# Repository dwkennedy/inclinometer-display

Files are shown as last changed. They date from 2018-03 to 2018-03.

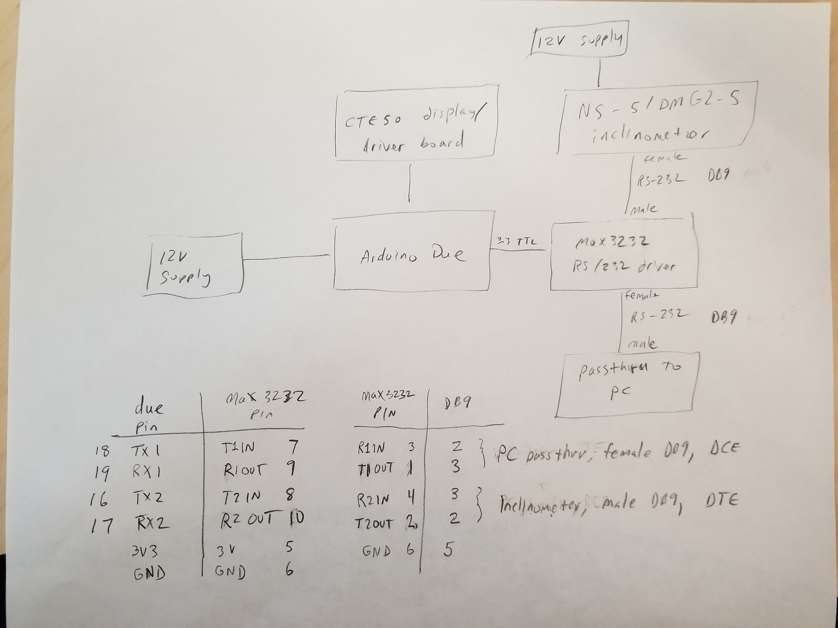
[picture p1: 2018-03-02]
inclinometer display block diagram and pinouts.jpg

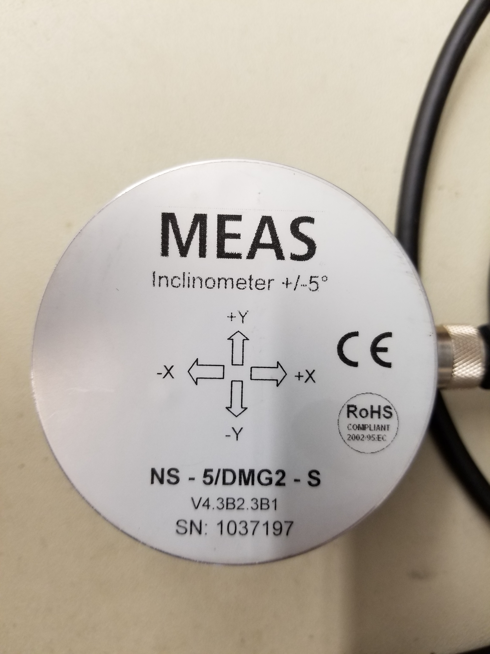
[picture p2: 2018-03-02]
measurement specialties inclinometer device.jpg

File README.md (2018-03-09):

# inclinometer-display
Device to display output from measurement specialties inclinometer

This device provides a graphical display of inclinometer output for leveling truck mounted RADAR systems (and anything else
one might desire)

Hardware requirements:
     Arduino DUE or similar.  I used a sainsmart clone
     
     MAX3232 on tx1/rx1 and tx2/rx2 for RS-232 level shifting. 
     one option: sparkfun transceiver breakout - MAX3232.  P/N BOB-11189
     https://www.sparkfun.com/products/11189
     
     DB9 connecters (male on tx2/rx2, female for tx1/rx1 passthru)
     
     measurement specialties NS-5/DMG2-S inclinometer
     
     sainsmart LCD driver and LCD panel SKU: 20-011-D20  
     https://www.sainsmart.com/products/sainsmart-due-5-lcd-touch-panel-sd-card-slot-tft-lcd-shield-kit-for-arduino
     
     12VDC, 500mA power supply with barrel connector -or- 5VDC, 1A with micro USB connector
     
Software requirements:
     GroteskBold32x64.c was downloaded from http://www.rinkydinkelectronics.com/r_fonts.php
     The excellent UTFT library from http://www.rinkydinkelectronics.com/library.php?id=51
     
     Note for UTFT installation/configuration, usage with CTE DUE shield:
         1.uncomment "#define CTE_DUE_SHIELD 1" in the HW_ARM_defines.h in the \hardware\arm folder of the UTFT library
         2.Change the pinout to : UTFT myGLCD(CTE50,25,26,27,28);
  
System description:
  
  The Arudino DUE is connected to the MAX3232 to provide two RS-232 serial ports.  One port is connected to the inclinometer device,
  the other port provides a transparent passthru for an attached PC (for configuration of the inclinometer and/or monitoring with
  the PC software)
  
  On boot, the Arudino code attempts to order the inclinometer to begin sending measurements continuously.  It is assumed that the
  inclinometer has been previously set to provide 2 Hz updates, appropriate filtering settings, and a 9600 baud rate.  Without the
  correct baud rate, the PC passthru port will not work.  The PC  must also be set to 9600 baud.  The inclinometer also has 
  programmable level offsets, so it will report X=0 and Y=0 when the truck is in the desired orientation (i.e. level)
  
  The software then eavesdrops on the incoming "X=+8.888" and "Y=+8.888" format messages and displays them in a digital display, as
  well as a graphical dot on a ring/crosshair display.  The dot position is not linear, the graph is scaled with a sigmoid function so
  the center of the graph is more sensitive than the outside edges.  After I install in the truck, i need to tweak LEVEL_SIGMOID
  so the system is easy to use, and maybe plot a degree scale on the concentric rings.
  
  If the software doesn't hear a new message within so many milliseconds (INCLINOMETER_TIMEOUT), the possibly misleading dot is
  removed from the display, the X/Y angles are set to a MISSING_VALUE (9.999) and a flashing message is presented (NOT UPDATING). 
  This would usually be caused by the inclinometer data cable being unplugged, or the power is not on to the inclinometer.
  
  Just FYI version 1.0 had a 2x20 dot matrix LCD display, and vastly inferior in many other ways :)
  
CHANGELOG

3/9/2018:  inclinometer3.ino has a landscape display instead of portrait

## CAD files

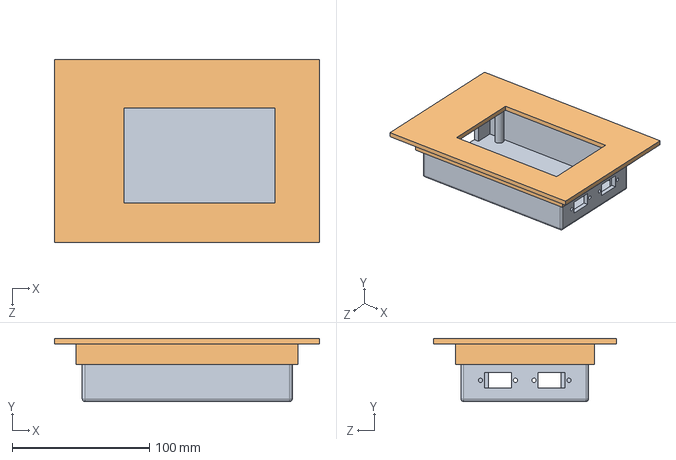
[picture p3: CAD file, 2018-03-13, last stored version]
Assem1.SLDASM
193.0 x 46.0 x 133.0 mm

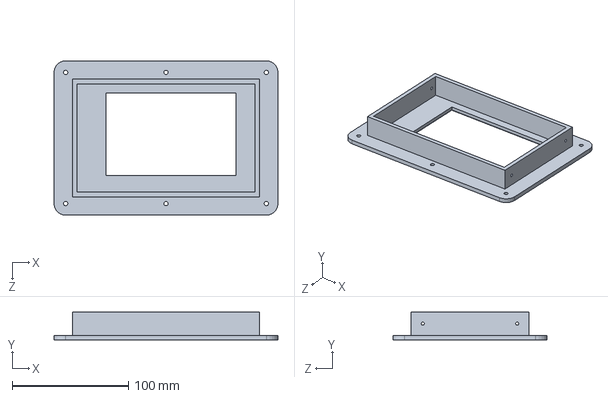
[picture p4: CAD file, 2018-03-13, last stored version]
Part5.SLDPRT
193.0 x 24.0 x 133.0 mm

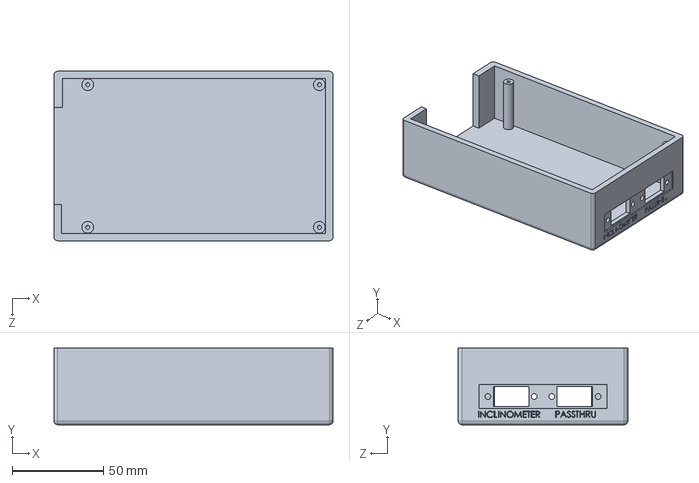
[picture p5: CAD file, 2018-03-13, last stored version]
Part4.SLDPRT
153.0 x 42.0 x 93.0 mm

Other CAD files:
Part4.STL
Part5.STL

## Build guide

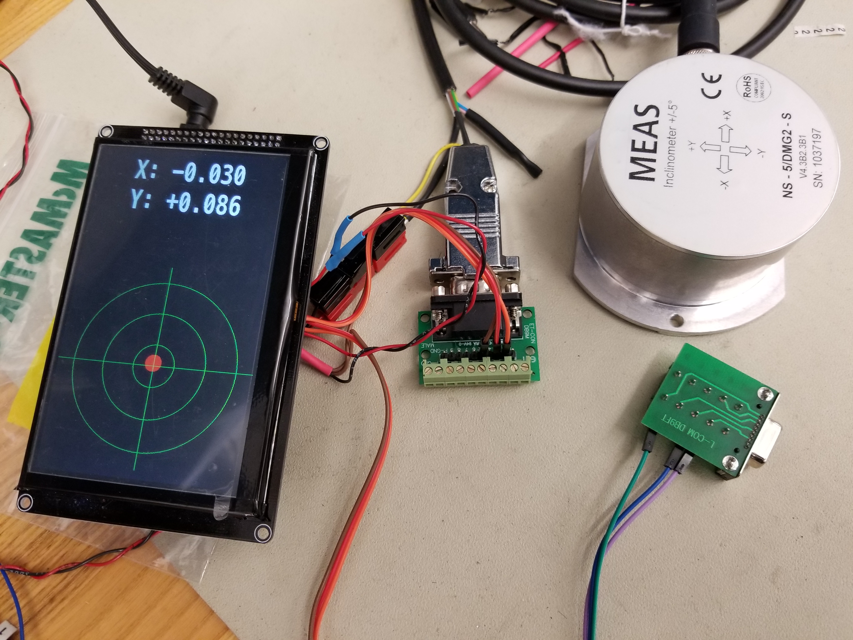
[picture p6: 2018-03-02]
inclinometer system, assembled without enclosure.jpg

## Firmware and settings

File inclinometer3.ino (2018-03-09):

/*
  
  inclinometer display sketch

  take inclinometer input from Serial2
  copy to/from Serial1 (for passthru when using PC software)
  update SainSmart 5" touch LCD
  hardware requirements:
     arduino DUE
     MAX3232 on tx1/rx1 and tx2/rx2 for RS-232 level shifting.
     DB9 connecters (male on tx2/rx2, female for tx1/rx1 passthru)
     measurement specialties NS-5/DMG2-S inclinometer
     sainsmart LCD driver and LCD panel SKU: 20-011-D20  
     https://www.sainsmart.com/products/sainsmart-due-5-lcd-touch-panel-sd-card-slot-tft-lcd-shield-kit-for-arduino
     12VDC, 500mA power supply with barrel connector -or- 5VDC, 1A with micro USB connector

  now modified for landscape orientation
  
  created 1 March 2018
  by Doug Kennedy
*/

#include <UTFT.h>

// Declare which fonts we will be using
//extern uint8_t SmallFont[];
//extern uint8_t SevenSegNumFont[];
extern uint8_t BigFont[];
extern uint8_t GroteskBold32x64[];

// Set the pins to the correct ones for your development shield
// ------------------------------------------------------------
// Standard Arduino Mega/Due shield            : <display model>,38,39,40,41
// CTE TFT LCD/SD Shield for Arduino Due       : <display model>,25,26,27,28
// Teensy 3.x TFT Test Board                   : <display model>,23,22, 3, 4
// ElecHouse TFT LCD/SD Shield for Arduino Due : <display model>,22,23,31,33
//
// Remember to change the model parameter to suit your display module!

UTFT myGLCD(CTE50,25,26,27,28);
// dimensions of screen
//#define HEIGHT 800
//#define WIDTH 480
#define HEIGHT 480
#define WIDTH 800
// coordinates of center of level bubble
//#define LEVEL_X_CENTER (WIDTH/2)
//#define LEVEL_Y_CENTER ((HEIGHT/2)+140)
#define LEVEL_X_CENTER (HEIGHT/2)
#define LEVEL_Y_CENTER (HEIGHT/2)
// rings
#define LEVEL_RADIUS1 50
#define LEVEL_RADIUS2 125
#define LEVEL_RADIUS3 200
// max range of inclinometer, in degrees +/-
#define LEVEL_RANGE 8
// pixels per degree (inclinometer reads in degrees +/-)
#define LEVEL_SCALE (HEIGHT/(2*LEVEL_RANGE))
// "spread" of function, makes center more sensitive.  Bigger is less sensitive.
// LEVEL_SIDMOID=0.5:  0.5 degree per range ring
// LEVEL_SIGMOID=1.0:  1.0 degree per range ring
// LEVEL_SIGMOID=2.0:  2.0 degree per range ring (approx)
#define LEVEL_SIGMOID 2

// how many millis before reporting inclinometer data missing
#define INCLINOMETER_TIMEOUT 3000
// how fast to blink the TIMEOUT message (in millis)
#define BLINK_RATE 500

// handy inline function
#define SIGN(a) (((a) > 0) ? '+' : '-')
 
String inputString = "";         // a String to hold incoming data stream
String outputString1 = "";        // a String to build output
String outputString2 = "";        // a String to build output
boolean stringComplete = false;  // whether the string is complete
float inclinometerX, inclinometerY;  // hold last values of inclinometer output
float oldInclinometerX, oldInclinometerY;  // extra copy in case of output error (zero)
int bubbleX, bubbleY;              // center of plotted bubble, in pixels
unsigned long timeout;           // keep track of last inclinometer message
boolean timeoutFlag = false;     // display TIMEOUT message (true) or not (false)

void setup() {
  Serial1.begin(9600);
  Serial2.begin(9600);
  inputString.reserve(200);
  outputString1.reserve(20);
  outputString2.reserve(20);
  // force one update of the display; useful if inclinometer not sending messages (or unplugged)
  stringComplete = true;  
  // Setup the LCD
  // myGLCD.InitLCD(PORTRAIT);
  myGLCD.InitLCD(LANDSCAPE);
  //  myGLCD.setFont(SmallFont);
  //  myGLCD.setFont(SevenSegNumFont);
  myGLCD.setFont(GroteskBold32x64);
  myGLCD.clrScr();

  // print initialization message here
  myGLCD.print("NSSL/FOFS",CENTER,40);
  myGLCD.print("Inclinometer",CENTER,140);
  myGLCD.print("Display, v2.0",CENTER,240);
  myGLCD.print("http://github/dwkennedy", CENTER, 340);
  
  // initialize digital pin LED_BUILTIN as an output.
  pinMode(LED_BUILTIN, OUTPUT);

  Serial1.println("NSSL Inclinometer Display v2.0");
  Serial1.println("https://github.com/dwkennedy/inclinometer-display");
  Serial1.println("");
  Serial1.print("setting inclinometer to continuous mode");

  // put inclinometer in continuous mode
  delay(1000);
  Serial2.write("F");
  Serial1.write(".");
  delay(750);
  Serial2.write("F");
  Serial1.write(".");
  delay(500);
  Serial2.write("F");
  Serial1.write(".");
  delay(500);
  Serial1.println();
    
  // empty buffer
  while (Serial2.available() ) {
    Serial2.read();
    delay(1);
  }

  // set initial missing values so we know it's not working yet
  
  inclinometerX = 9.999;
  inclinometerY = 9.999;
  oldInclinometerX = 9.999;
  oldInclinometerY = 9.999;
  
  myGLCD.clrScr();

  // initialize inclinometer read timeout
  timeout = millis();  
}

void loop() {
  static int page=0;
     
  if(stringComplete) {
    // parse string here

    inputString.trim();
    
    // debug code
    //Serial1.print("parse: ");
    //Serial1.println(inputString);

    //  save a copy of previous inclinometer readings, in case we get a parse error
    //     so we can roll back to the previous value
    oldInclinometerX = inclinometerX;
    oldInclinometerY = inclinometerY;
    
    if (inputString.startsWith("X=")) {
        // parse number, load into inclinometerX
        inclinometerX = inputString.substring(2).toFloat();
        if (inclinometerX == 0) {
          inclinometerX = oldInclinometerX;
        }
    } else if (inputString.startsWith("Y=")) {
        // parse number, load into inclinometerY
        inclinometerY = inputString.substring(2).toFloat();
        if (inclinometerY == 0) {
          inclinometerY = oldInclinometerY;
        }
    }


    // debug code
    // Serial1.print(inputString);
    //Serial1.print("X = ");
    //Serial1.print(inclinometerX, 3);
    //Serial1.print(": Y = ");
    //Serial1.println(inclinometerY, 3);

    // skip to next sentence in string (if there is one)
    inputString = inputString.substring(inputString.indexOf('\n'));
    inputString.trim();
    
    stringComplete = (inputString.length() > 0);  // still characters left => stringComplete is true

    //debug code
    //Serial1.print("remain: ");
    //Serial1.println(inputString);

    if (!stringComplete) {  // only update if we read a new message, and are now out of sentences in buffer
      timeoutFlag = false;  // erase timeout messgae
      updateDisplay();
      timeout = millis();  // update timeout
    }
  } else {
    // message not received, check timeout
    if ((millis() - timeout) > INCLINOMETER_TIMEOUT) {
      // timeout; set inclinometer values to missing 
      inclinometerX = 9.999;
      inclinometerY = 9.999;
      timeoutFlag = !timeoutFlag;  // blink timeout message
      updateDisplay();  //    and force display update
      // don't erase/redraw missing bubble
      bubbleX = -1;
      bubbleY = -1;
      timeout = millis() - INCLINOMETER_TIMEOUT + BLINK_RATE;     // update timer (so we don't constantly redraw while in timeout)
    }
  }
}

// copy characters from passthru port to inclinometer
void serialEvent1() {
  while (Serial1.available()) {
    Serial2.write(Serial1.read());
  }
}

// read from inclinometer
void serialEvent2() {
  static int state;

  digitalWrite(LED_BUILTIN, state);
  state = !state;
  
  while (Serial2.available()) {
    // get the new byte:
    char inChar = (char)Serial2.read();
    // echo to Serial1
    Serial1.write(inChar);   
    // add it to the inputString:
    inputString += inChar;
    // if the incoming character is a newline, set a flag so the main loop can
    // do something about it:
    if (inChar == '\n') {
      stringComplete = true;
    }
  }
}

// redraw the display
void updateDisplay() {
  
  // double buffering -- not implemented on CTE50 display
  //if (page == 0) {
  //  page = 1;
  //} else {
  //  page = 0;
  //}
    
  //myGLCD.setWritePage(page);
  //myGLCD.clrScr();
   
  // update numbers; multiply/divide to get rid of freakiness
  //  and by freakiness I mean ambiguity in sign when very close to zero 
  outputString1 = String("X: ") + String(SIGN(inclinometerX*1000)) + String(abs(inclinometerX*1000)/1000,3);
  outputString2 = String("Y: ") + String(SIGN(inclinometerY*1000)) + String(abs(inclinometerY*1000)/1000,3);
  myGLCD.setColor(255, 255, 255);
  myGLCD.setBackColor(0, 0, 0);
  //myGLCD.print(outputString1, CENTER, 20);
  //myGLCD.print(outputString2, CENTER, 100);
  myGLCD.print(outputString1, RIGHT, 20);
  myGLCD.print(outputString2, RIGHT, 100);

  // update level bubble

  // erase bubble
  myGLCD.setColor(0,0,0);
  myGLCD.fillCircle(bubbleX, bubbleY, 20);

  if ((inclinometerX < 9.998) && (inclinometerY < 9.998)) {
    // draw new bubble; bubbleX and bubbleY are in units of pixels and include display center offset
    bubbleX = LEVEL_X_CENTER + LEVEL_SCALE*((2*LEVEL_RANGE/(1+exp(-inclinometerX/LEVEL_SIGMOID))) - LEVEL_RANGE);
    bubbleY = LEVEL_Y_CENTER - LEVEL_SCALE*((2*LEVEL_RANGE/(1+exp(-inclinometerY/LEVEL_SIGMOID))) - LEVEL_RANGE);
    //bubbleX = LEVEL_X_CENTER + LEVEL_SCALE*((2*LEVEL_RANGE/(1+exp(-inclinometerY/LEVEL_SIGMOID))) - LEVEL_RANGE);   // landscape?
    //bubbleY = LEVEL_Y_CENTER + LEVEL_SCALE*((2*LEVEL_RANGE/(1+exp(-inclinometerX/LEVEL_SIGMOID))) - LEVEL_RANGE);   // landscape?
    myGLCD.setColor(255,0,0);
    myGLCD.fillCircle(bubbleX, bubbleY, 20);  // portrait
    //myGLCD.fillCircle(bubbleX, bubbleY, 20);  // landscape?
  } 
      
  // range rings
  myGLCD.setColor(0,255,0);
  myGLCD.drawCircle(LEVEL_X_CENTER, LEVEL_Y_CENTER, LEVEL_RADIUS1);
  myGLCD.drawCircle(LEVEL_X_CENTER, LEVEL_Y_CENTER, LEVEL_RADIUS2);
  myGLCD.drawCircle(LEVEL_X_CENTER, LEVEL_Y_CENTER, LEVEL_RADIUS3);
  // crosshairs
  myGLCD.drawLine(LEVEL_X_CENTER, LEVEL_Y_CENTER-HEIGHT/2, LEVEL_X_CENTER, LEVEL_Y_CENTER+HEIGHT/2);
  myGLCD.drawLine(LEVEL_X_CENTER-HEIGHT/2, LEVEL_Y_CENTER, LEVEL_X_CENTER+HEIGHT/2, LEVEL_Y_CENTER);

  // draw or erase TIMEOUT message
  if (timeoutFlag) {
    myGLCD.setColor(255,0,0);
//    myGLCD.print("NOT UPDATING",CENTER, 200);
    myGLCD.print("NOT   ", RIGHT, 320);
    myGLCD.print("UPDATING!", RIGHT, 400);
  } else {
    // erase NOT UPDATING message
    myGLCD.setColor(0,0,0);
//    myGLCD.fillRect(0,180,WIDTH,264);
    myGLCD.fillRect(WIDTH-290, 320, WIDTH, 480);
  }
  //myGLCD.setDisplayPage(page);
}
